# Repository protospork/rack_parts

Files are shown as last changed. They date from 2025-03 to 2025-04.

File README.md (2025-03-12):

# rack_parts
I'm posting the models I used for my 10" mini-rack project here. With two exceptions* these are all my own designs.

(* The optiplex/thinkcentre shelf is a remix of [a design found on onshape from user "salemz"](https://cad.onshape.com/documents/edc2be91c8a5c8ce739145d0/w/da46e5e176b4d39cc755736e/e/9c80555ae34e66083f173074). The 5.25" brackets are remixed from [this hardwarehaven model](https://www.thingiverse.com/thing:6859441) and intended to be installed inside/over a deskpi 1U rack shelf for support.

The rack:
an 8U minirack

All panel designs conform to this very professional design doc:
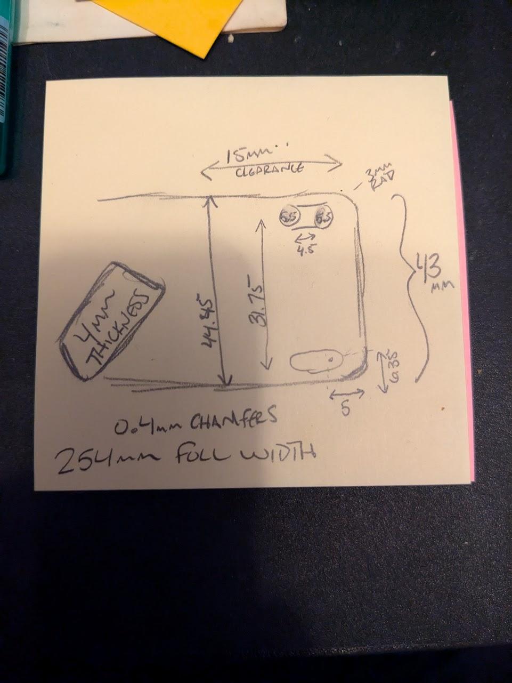
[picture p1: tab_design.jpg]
a post-it note


I've been running three micro PCs for a while and when I saw all of the initial 10" rack coverage last fall/winter (particularly hardwarehaven's 3d printed setup) I decided to plan my own build. I didn't originally intend to use the Geeekpi rack but it had a price drop around the same time I was getting frustrated pricing out different panel/enclosure options for my rack-rail skeleton.  
So, I transplanted everything into the Deskpi but it's extremely shallow so I reused two rack rails to add about 50mm to the total depth of the setup.  
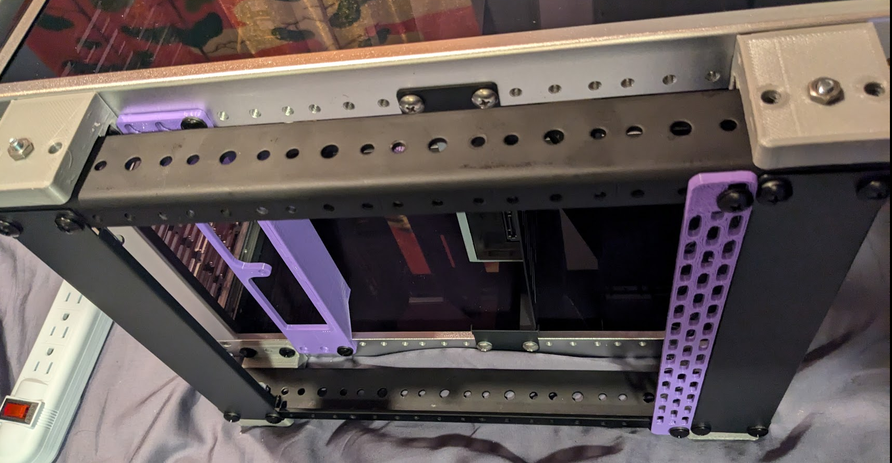
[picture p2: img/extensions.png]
close up of the extension being test-fit
  
It was important to me that this thing stay as enclosed and cat-proof as possible, as well as having as few wires leaving it as I could get away with. The rear panel arrangement holds a [4-spot power strip](https://www.amazon.com/dp/B07XXLPNJ7), facing inward, as well as a 120mm exhaust fan.  
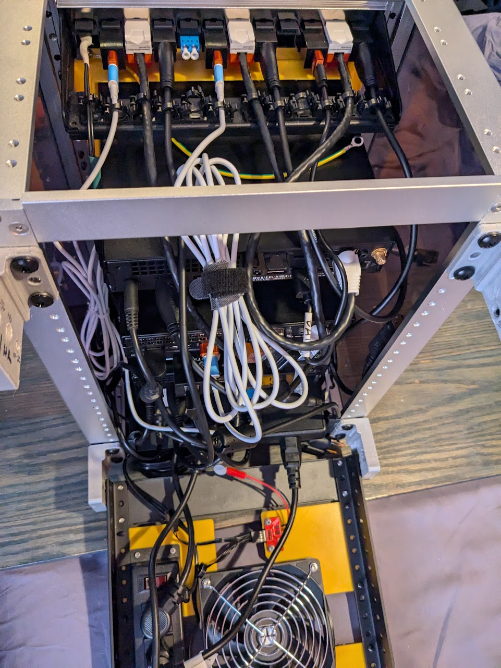
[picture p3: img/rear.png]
rack from behind
  
All 3 PC power bricks live in the bottom 2U along with a [Meanwell RS-50-12](https://www.digikey.com/en/products/detail/mean-well-usa-inc/RS-50-12/7706187) to power the fan, network switch, and the USB adapter for the bluray drive.  
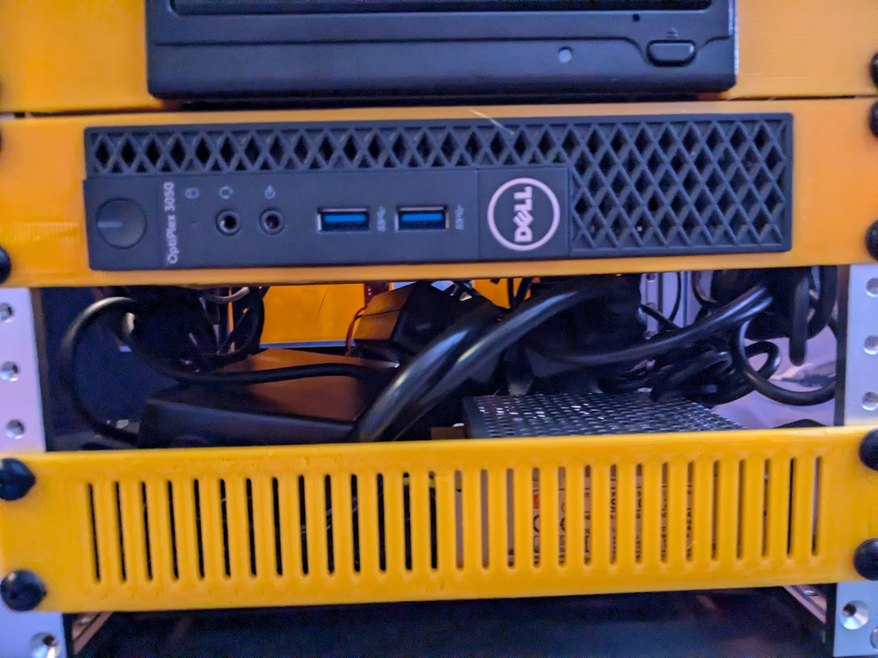
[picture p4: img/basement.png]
front view looking into the unsecured pile of power bricks and cables
  
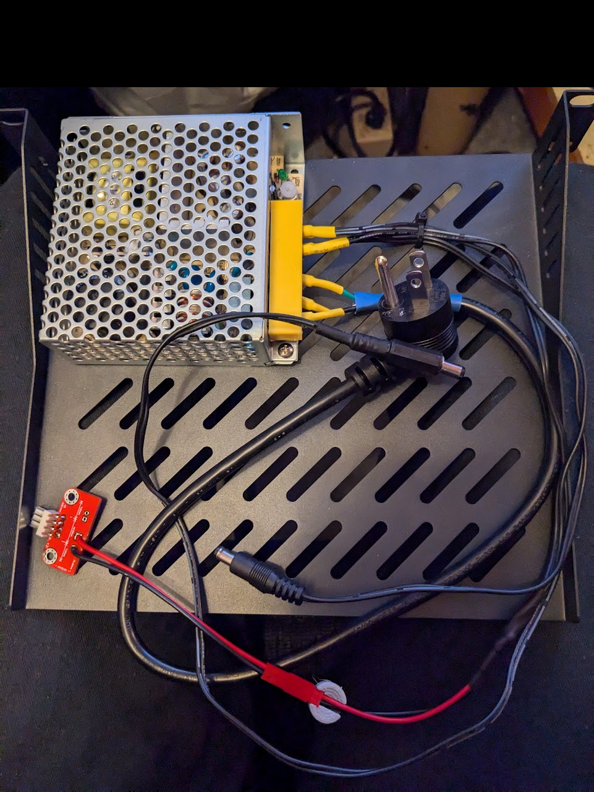
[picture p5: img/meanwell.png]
the meanwell PSU screwed down to the shelf. that fan adapter is a custom pcb sorry
  

The [patch panel](https://www.amazon.com/dp/B0CMGN4X58) sits a few millimeters out from everywhere else because it's got a couple of protruding metal tabs that make it too wide for the Rackpi's rails. I printed little shims to make it fit evenly. It's set up with a network, USB, and HDMI passthrough for each of the 3 computers. The USB passthroughs were completely unnecessary because they all have front panel ports. The Thinkcentre's HDMI jack is not hooked up because that machine only has displayport (😠). The other 3 ports are: 1 blank, 1 custom 5mm dc barrel jack passthrough for the switch's power, and 1 fiber optic passthrough.  
  
All three computers have 2.5Gbit M.2 NICs in them, and the [switch](https://www.amazon.com/dp/B0CFTDLDQL) is 2.5Gbit as well as an SFP+ fiber link to my other 2.5Gbit/SFP+ switch.

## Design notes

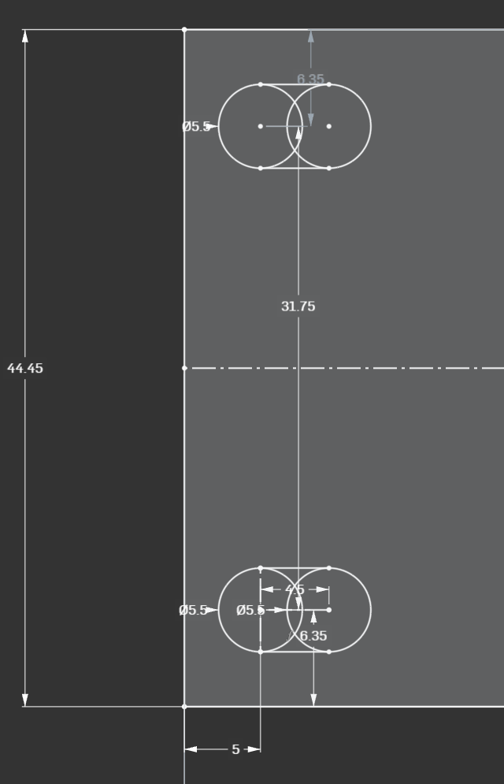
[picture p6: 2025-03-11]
tab_clean.png

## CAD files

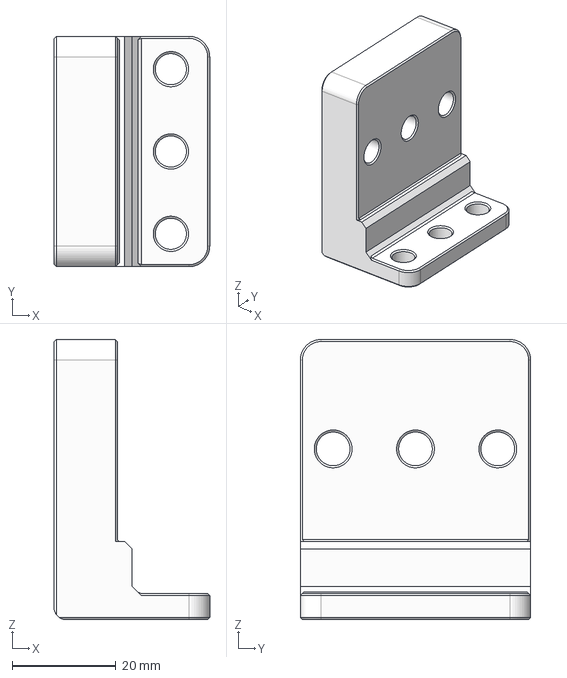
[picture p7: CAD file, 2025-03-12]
STEP/deskpi extension v1.step
30.0 x 44.5 x 54.0 mm

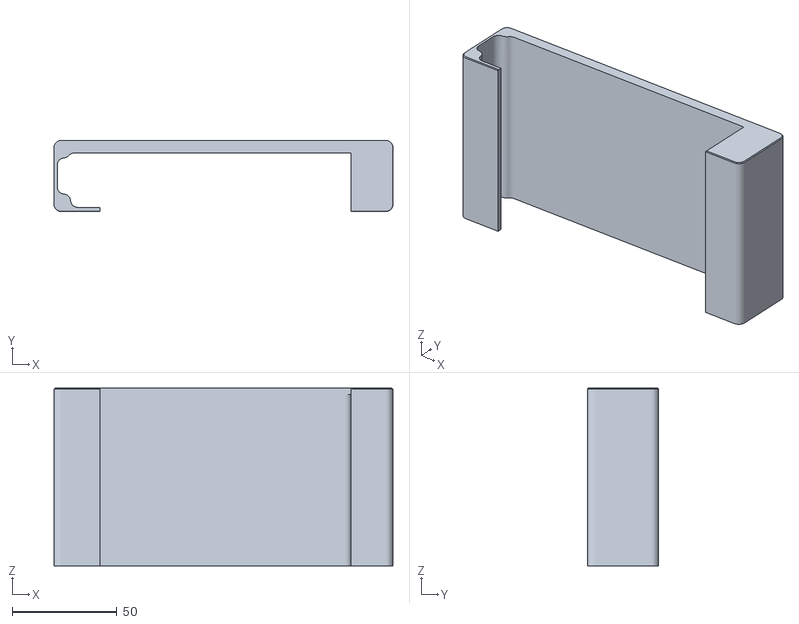
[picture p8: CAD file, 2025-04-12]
STL/nicgiga adapter s25-0402-n.stl
162.2 x 34.0 x 85.0

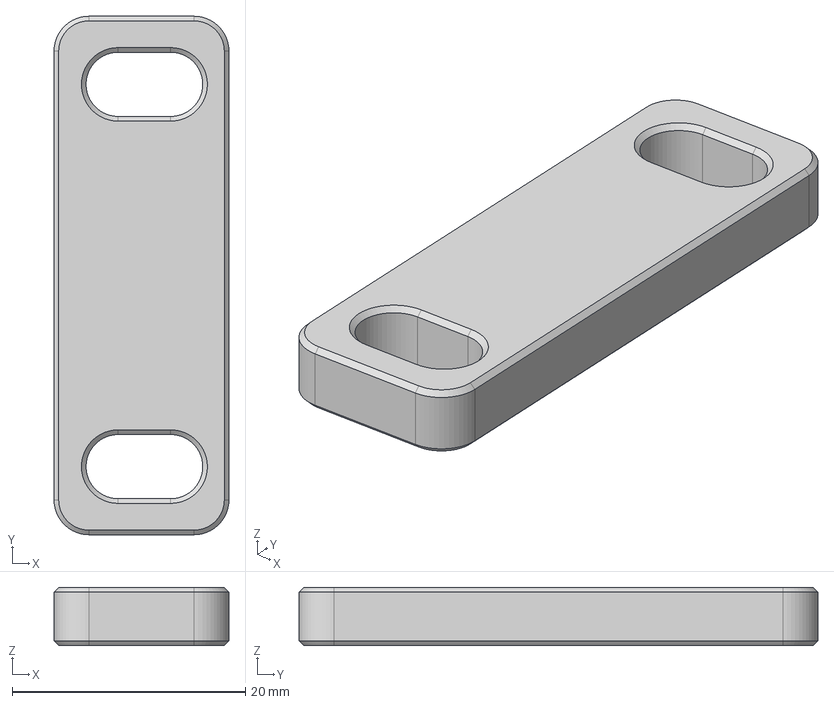
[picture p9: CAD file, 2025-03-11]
STEP/10 inch rack brackets - patch panel shim.step
15.0 x 44.5 x 5.00 mm

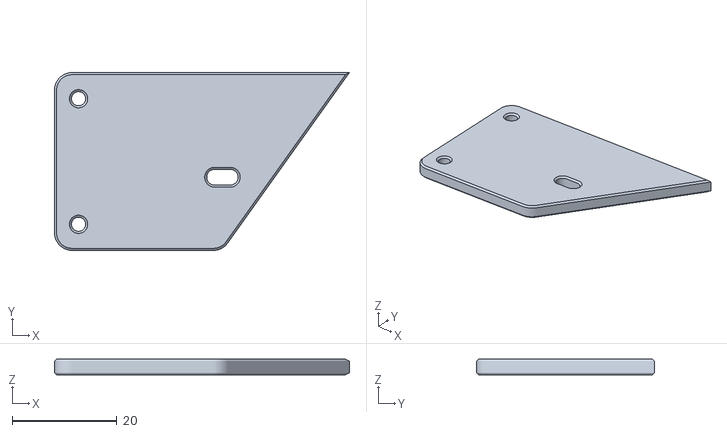
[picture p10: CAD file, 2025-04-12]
STL/nicgiga rear-compact s25-0402-n.stl
56.4 x 34.0 x 3.00

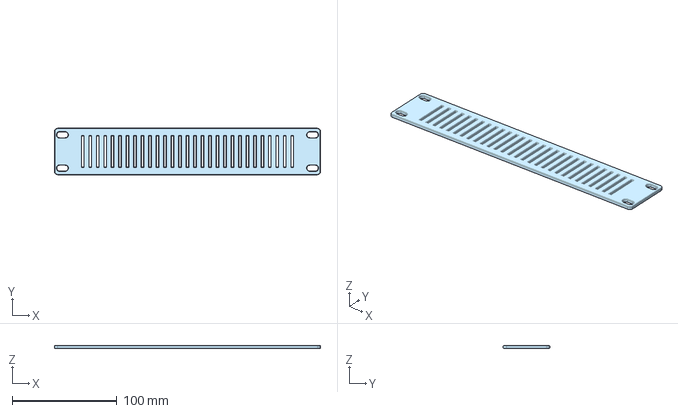
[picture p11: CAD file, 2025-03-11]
STEP/10 inch rack brackets - 1U vented blank 3mm.step
254.0 x 44.4 x 3.00 mm

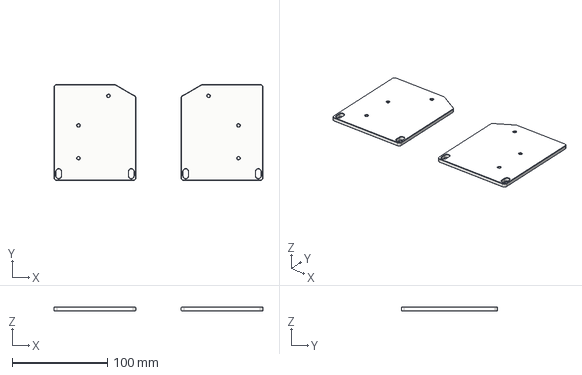
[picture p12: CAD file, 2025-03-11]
STEP/powerstrip mount.step
219.3 x 101.0 x 4.00 mm

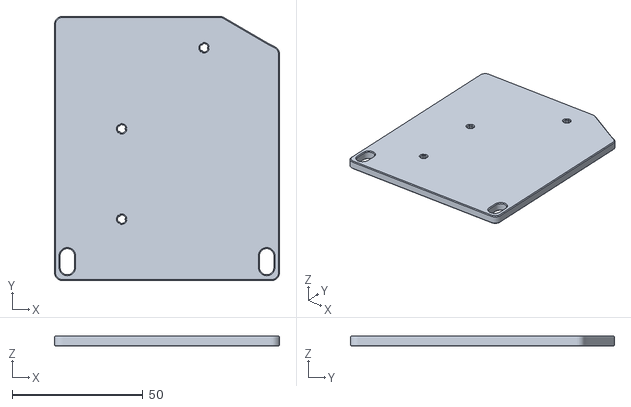
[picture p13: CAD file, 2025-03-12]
STL/rearpanel - 5U vertical power strip top.stl
86.0 x 101.0 x 4.00

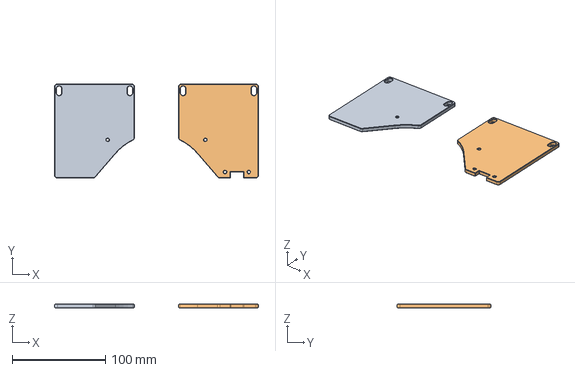
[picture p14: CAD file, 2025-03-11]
STEP/powerstrip fan mount.step
219.3 x 101.0 x 4.00 mm

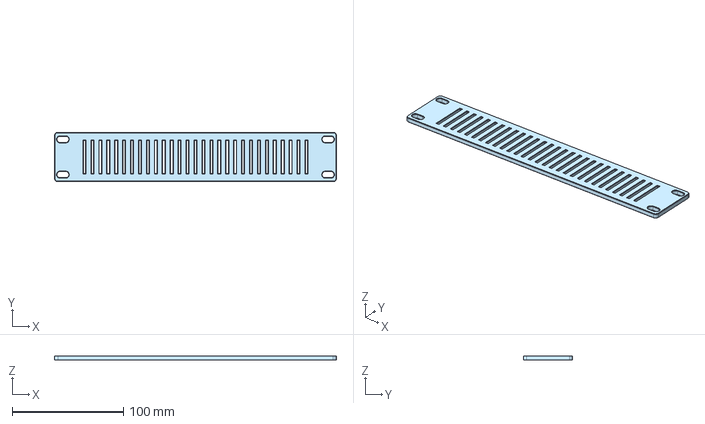
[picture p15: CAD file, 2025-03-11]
STEP/10 inch rack brackets - 1U vented blank 4mm.step
254.0 x 44.4 x 4.00 mm

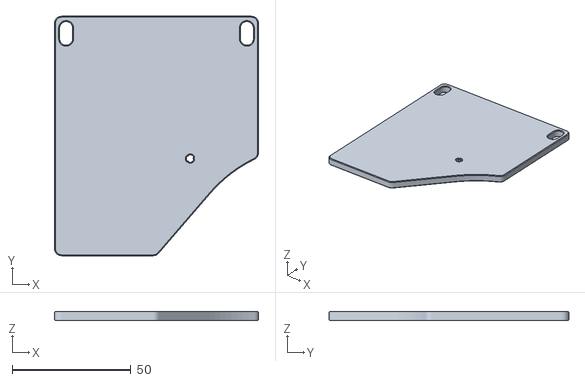
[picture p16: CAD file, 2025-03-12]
STL/rearpanel - 5U vertical opposite fan side top.stl
86.0 x 101.0 x 4.00

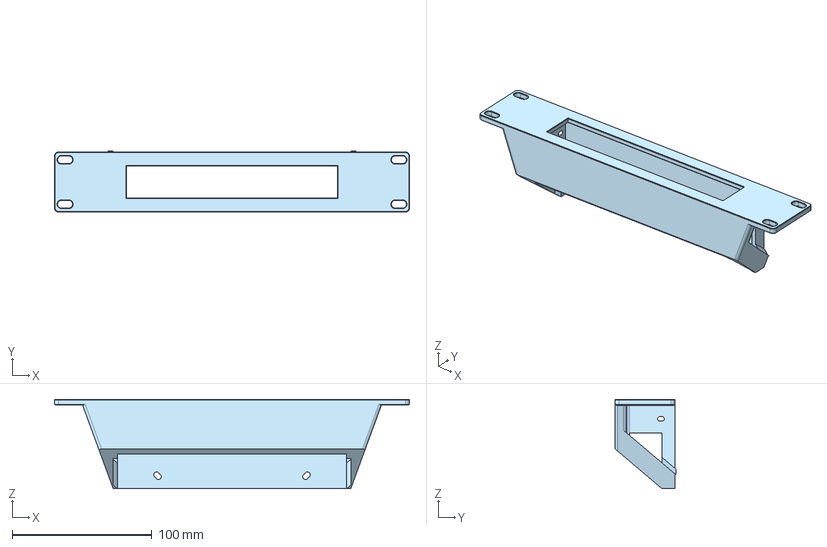
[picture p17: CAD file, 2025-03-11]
STEP/10 inch rack brackets - ienron hg0402xg (v4~recovered).step
254.0 x 43.7 x 64.0 mm

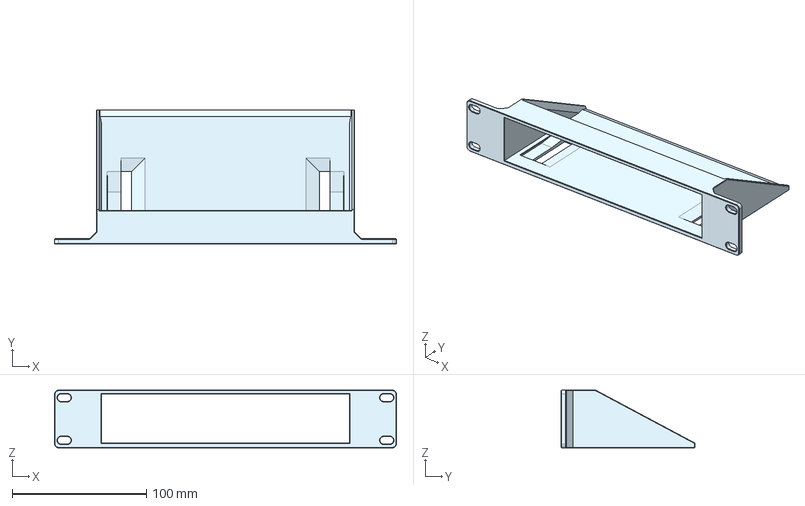
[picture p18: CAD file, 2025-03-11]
STEP/10 inch rack - optiplex thinkcentre combo.step
254.8 x 100.0 x 43.0 mm

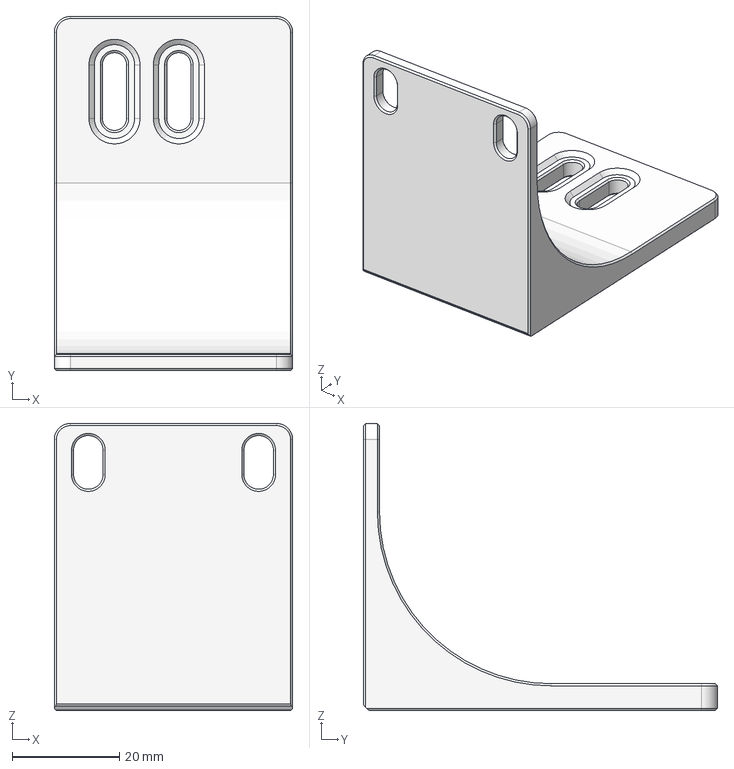
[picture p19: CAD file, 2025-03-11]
STEP/10 inch rack - cdrom_-_left bracket.step
44.5 x 66.0 x 53.5 mm

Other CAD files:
STL/deskpi extension (built for M5 or 10-32 inserts).stl
STL/3mm blank vented.stl
STL/rearpanel - 5U vertical power strip bottom.stl
STL/ienron switch bracket.stl
STL/4mm blank vented.stl
STEP/10 inch rack - cdrom_-_right bracket.step
STL/10 inch rack - cdrom_-_left bracket.stl
STL/10 inch rack - cdrom_-_right bracket.stl
STL/10 inch rack - optiplex or thinkcentre.stl
STL/patch panel shim.stl
STL/rearpanel - 5U vertical opposite fan side bottom.stl

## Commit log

2025-03-12 Create deskpi extension v1.step
    [deskpi extension v1.step]
2025-03-12 adding stl files
    the filenames don't match the .steps sorry good luck
    [10 inch rack - optiplex or thinkcentre.stl, 3mm blank vented.stl, 4mm blank vented.stl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]
2025-03-12 figured out where those vented plates came from
    it was me lol
2025-03-12 correct revision this time
    [10 inch rack - cdrom_-_left bracket.stl, 10 inch rack - cdrom_-_right bracket.stl]
2025-04-12 added nicgiga switch adapters
    adapts nicgiga s25-0402-n switch to the ienron bracket
    step files and updated model with screw holes soon
    [nicgiga adapter s25-0402-n.stl, nicgiga rear-compact s25-0402-n.stl]
